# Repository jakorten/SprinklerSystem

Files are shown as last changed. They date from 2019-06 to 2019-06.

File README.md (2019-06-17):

# SprinklerSystem
Repository for valve controllers etc.

Here I publish updates to Python and Arduino scripts to create my / your own irrigation system.

## System parts
CinqueValvoleHAT is used to control a pump system.
TinyRelayModule is used to control a larger (230V) relay to switch of the main pump.
DueValvoleZeroBoard is used to control two valves and also features sensors.

## Progress and links

June 2019:
- CinqueValvoleHAT: 5x Valve/Tap Controller board (v1.0 / v1.1) (https://github.com/jakorten/SprinklerSystem/tree/master/CinqueValvoleHAT)
- DueValvoleZeroBoard: 2x Valve/Tap under development, uses a SAMD21 microcontroller and interfaces with a Raspberry Pi Zero (W).
- TinyRelayModule is only a solderboard version for now.

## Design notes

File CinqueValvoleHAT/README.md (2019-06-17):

# SprinklerSystem: CinqueValvoleHAT
Repository for valve controllers etc.

## About
Here I publish updates to Python and Arduino scripts to create my / your own irrigation system.

June 2019:
- 5x Tap Controller board (v1.0 / v1.1) (CinqueValvoleHAT)

The CinqueValvoleHAT is used to control up to 5 valves.
- Typical valves have DC motors
- They will switch of when the limit is reached (fully open or fully closed)
- The print was designed to control 12V valves

Other DC motors can also be controlled using this HAT.
We have tested the HAT for 12V and below.

Most parts can handle up to 50V but that is the maximum, of you would
want to control 48V you should change some parts:
- 0.1uF/50V
- 22uF/63V

We use a voltage divider in v1.1 for AOD417, for 12V that would not have been
necessary. The AOD417 protects against wrong polarity.

The input (suggested 5V - 12V) is not connected to the rest of the system only to the
DRV8871 drivers.

Each DRV8871 can handle up to 3.6A (but is limited to about 2A by the 30k resistors) and
has a maximum voltage of 50V (< 45V recommended). In case you want to use the HAT as is
for 48V motors we suggest you make sure your supply only divers 45V or less which should
be more than enough for ball valves. Note: We did not test this so use at your own risk.

We did try to run our 12V ball valves at 7V and although they move slower they will work
just fine.

We used the valves from:
https://nl.aliexpress.com/store/4032047?spm=a2g0o.detail.1000002.2.6d6b58daLNaQAn
(e.g. https://nl.aliexpress.com/item/32896353276.html?spm=a2g0s.9042311.0.0.32b34c4dLBPZam)

## Source
The source lets your Raspberry Pi control the valves via a PCA9685 IC

## Credits

Thanks @Adafruit for not only providing us with the basis idea and HAT layout (https://www.adafruit.com/product/2348).
Their hat works well but we found it got too hot inside the narrow enclosure we used.
Also thanks to @Adafruit for their suggestion to use DRV8871 drivers (they sell separate boards).

Note: we have designed the HAT and software to interoperate with homebridge. We use a second Raspberry Pi that
runs homebridge and will allow to set the valves remotely.

# ToDo: Work in progress
- We have created a HMI system for operation without homebridge
- We still need to integrate this functionality with the current source.
- Other parts of the system will be uploaded as we go.
- We hope to make the system available for purchase using Tindie.

Johan Korten<br>
June 2019

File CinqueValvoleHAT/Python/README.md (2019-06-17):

# SprinklerSystem: CinqueValvoleHAT
Controller for a CinqueValvoleHAT hat using python.

The controlServer.py will let you start a simple server on your Raspberry Pi.

http://hostname:8000/valves/valve=0&state=1 will set valve 1 to open
http://hostname:8000/valves/valve=0&state=0 will set valve 1 to closed

The tapHatCinqController defines five possible valves you can use.
You could stake more than one CinqueValvoleHAT but then you need a special stacking header of course.

We have not done that for now but it would be easy to change the source code to accommodate for that
(add parameter for your url that you e.g. call 'module', parse that variable and send commands to
the appropriate instance).

All taps have a timeout as defined in that init method:
self.motor1 = DRV8871_Valve(0, 15.0, tapState.open)

This means:
- self.motor1 is defined as motor 0
- has a timeout of 15.0 seconds
- default state is open (change to closed if you want to reverse how your valve reacts)

Johan Korten<br>
June 2019

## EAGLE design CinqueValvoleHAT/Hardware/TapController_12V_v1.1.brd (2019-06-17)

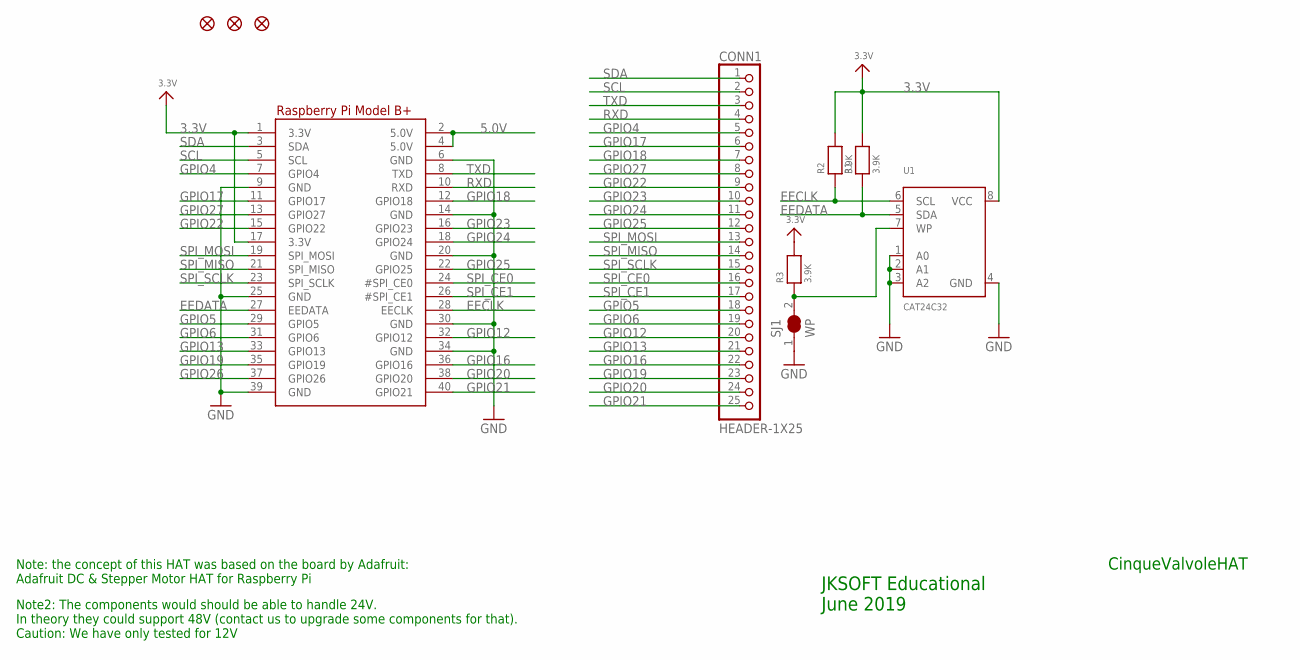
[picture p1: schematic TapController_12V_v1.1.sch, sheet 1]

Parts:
CONN1: HEADER-1X25; 1X25_ROUND_70MIL
FID1, FID2, FID3: FIDUCIAL""; FIDUCIAL_1MM
R1, R2, R3: 3.9K; 0805-NO@1
RPI1: RASPBERRYPI_BPLUS_HATSLOTS; PI_HAT_SLOTS
SJ1: WP; SOLDERJUMPER_CLOSEDWIRE
U1: CAT24C32; SOIC8_150MIL

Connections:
3.3V: R1.2, R2.2, R3.2, RPI1.1 (3.3V), RPI1.17 (3.3V), U1.8 (VCC); also elsewhere on the board
5.0V: RPI1.2 (5.0V), RPI1.4 (5.0V)
EECLK: R2.1, RPI1.28 (EECLK), U1.6 (SCL)
EEDATA: R1.1, RPI1.27 (EEDATA), U1.5 (SDA)
GND: RPI1.6 (GND), RPI1.9 (GND), RPI1.14 (GND), RPI1.20 (GND), RPI1.25 (GND), RPI1.30 (GND), RPI1.34 (GND), RPI1.39 (GND), SJ1.1, U1.1 (A0), U1.2 (A1), U1.3 (A2), U1.4 (GND); also elsewhere on the board
GPIO4: CONN1.5, RPI1.7 (GPIO4)
GPIO5: CONN1.18, RPI1.29 (GPIO5)
GPIO6: CONN1.19, RPI1.31 (GPIO6)
GPIO12: CONN1.20, RPI1.32 (GPIO12)
GPIO13: CONN1.21, RPI1.33 (GPIO13)
GPIO16: CONN1.22, RPI1.36 (GPIO16)
GPIO17: CONN1.6, RPI1.11 (GPIO17)
GPIO18: CONN1.7, RPI1.12 (GPIO18)
GPIO19: CONN1.23, RPI1.35 (GPIO19)
GPIO20: CONN1.24, RPI1.38 (GPIO20)
GPIO21: CONN1.25, RPI1.40 (GPIO21)
GPIO22: CONN1.9, RPI1.15 (GPIO22)
GPIO23: CONN1.10, RPI1.16 (GPIO23)
GPIO24: CONN1.11, RPI1.18 (GPIO24)
GPIO25: CONN1.12, RPI1.22 (GPIO25)
GPIO26: RPI1.37 (GPIO26)
GPIO27: CONN1.8, RPI1.13 (GPIO27)
unnamed: R3.1, SJ1.2, U1.7 (WP)
RXD: CONN1.4, RPI1.10 (RXD)
SCL: CONN1.2, RPI1.5 (SCL); also elsewhere on the board
SDA: CONN1.1, RPI1.3 (SDA); also elsewhere on the board
SPI_CE0: CONN1.16, RPI1.24 (#SPI_CE0)
SPI_CE1: CONN1.17, RPI1.26 (#SPI_CE1)
SPI_MISO: CONN1.14, RPI1.21 (SPI_MISO)
SPI_MOSI: CONN1.13, RPI1.19 (SPI_MOSI)
SPI_SCLK: CONN1.15, RPI1.23 (SPI_SCLK)
TXD: CONN1.3, RPI1.8 (TXD)

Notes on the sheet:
JKSOFT Educational June 2019
CinqueValvoleHAT
Note: the concept of this HAT was based on the board by Adafruit: Adafruit DC & Stepper Motor HAT for Raspberry Pi
Note2: The components would should be able to handle 24V. In theory they could support 48V (contact us to upgrade some components for that). Caution: We have only tested for 12V

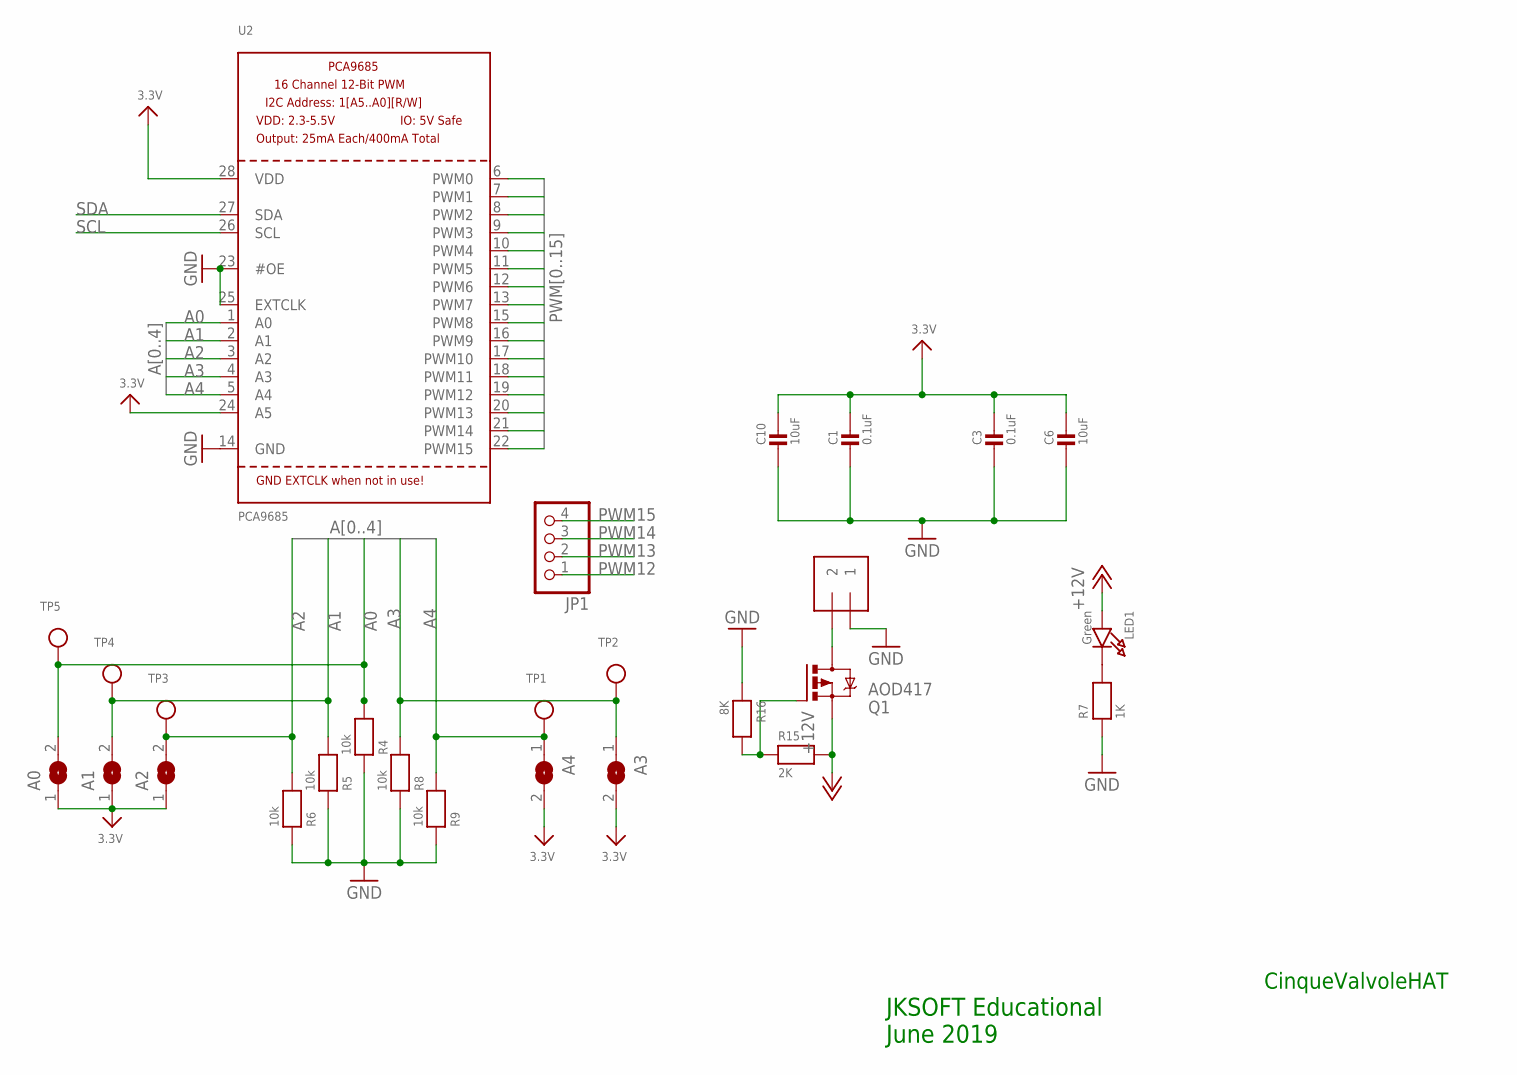
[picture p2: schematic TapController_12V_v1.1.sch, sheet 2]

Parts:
A0, A1, A2, A3, A4: SOLDERJUMPERREFLOW_NOPASTE; SOLDERJUMPER_REFLOW_NOPASTE
C1, C3: 0.1uF; 0805-NO
C6, C10: 10uF; 0805-NO
JP1: HEADER-1X476MIL; 1X04_ROUND_76
LED1: Green; CHIPLED_0805_NOOUTLINE
MPOWER: 1X2-3.5MM
Q1: AOD417; D-PAK_TO252AA
R4, R5, R6, R8, R9: 10k; 0805-NO@1
R7: 1K; 0805-NO@1
R15: 2K; 0805-NO@1
R16: 8K; 0805-NO@1
TP1, TP2, TP3, TP4, TP5: TESTPOINTROUND2MM; TESTPOINT_ROUND_2MM
U2: PCA9685; TSSOP28

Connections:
3.3V: A0.1, A1.1, A2.1, A3.2, A4.2, C1.1, C3.1, C6.1, C10.1, U2.24 (A5), U2.28 (VDD); also elsewhere on the board
12V: MPOWER.2, Q1.4 (D)
+12V: LED1.A, Q1.3 (S), R15.2; also elsewhere on the board
A0: A0.2, R4.2, TP5.P$1, U2.1 (A0)
A1: A1.2, R5.2, TP4.P$1, U2.2 (A1)
A2: A2.2, R6.2, TP3.P$1, U2.3 (A2)
A3: A3.1, R8.2, TP2.P$1, U2.4 (A3)
A4: A4.1, R9.2, TP1.P$1, U2.5 (A4)
GND: C1.2, C3.2, C6.2, C10.2, MPOWER.1, R4.1, R5.1, R6.1, R7.1, R8.1, R9.1, R16.1, U2.14 (GND), U2.23 (#OE), U2.25 (EXTCLK); also elsewhere on the board
unnamed: Q1.1 (G), R15.1, R16.2
unnamed: LED1.C, R7.2
PWM0: U2.6 (PWM0); also elsewhere on the board
PWM1: U2.7 (PWM1); also elsewhere on the board
PWM2: U2.8 (PWM2); also elsewhere on the board
PWM3: U2.9 (PWM3); also elsewhere on the board
PWM4: U2.10 (PWM4); also elsewhere on the board
PWM5: U2.11 (PWM5); also elsewhere on the board
PWM6: U2.12 (PWM6); also elsewhere on the board
PWM7: U2.13 (PWM7); also elsewhere on the board
PWM8: U2.15 (PWM8); also elsewhere on the board
PWM9: U2.16 (PWM9); also elsewhere on the board
PWM10: U2.17 (PWM10)
PWM11: U2.18 (PWM11)
PWM12: JP1.1, U2.19 (PWM12)
PWM13: JP1.2, U2.20 (PWM13)
PWM14: JP1.3, U2.21 (PWM14)
PWM15: JP1.4, U2.22 (PWM15)
SCL: U2.26 (SCL); also elsewhere on the board
SDA: U2.27 (SDA); also elsewhere on the board

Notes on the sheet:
JKSOFT Educational June 2019
CinqueValvoleHAT

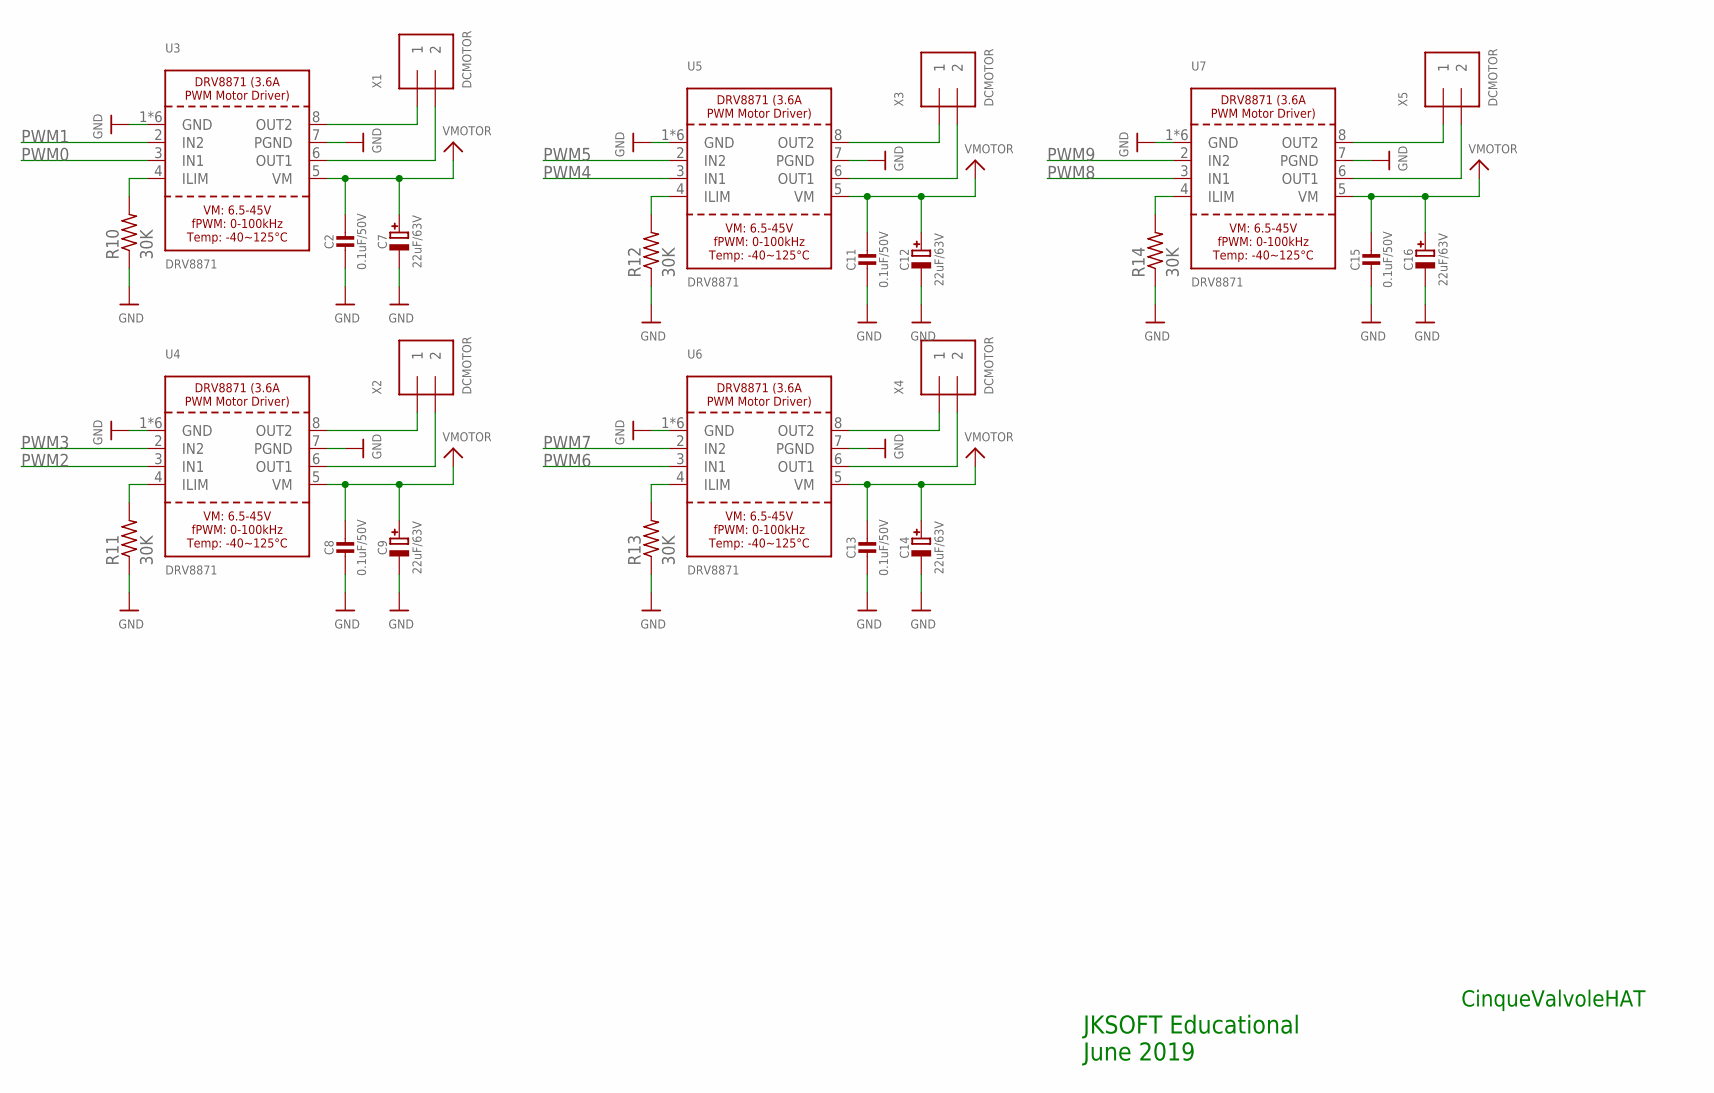
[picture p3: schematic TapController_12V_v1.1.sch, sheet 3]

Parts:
C2, C8, C11, C13, C15: 0.1uF/50V; 0805-NO
C7, C9, C12, C14, C16: 22uF/63V; PANASONIC_D
R10, R11, R12, R13, R14: 30K; R0805W
U3, U4, U5, U6, U7: DRV8871; HSOP8
X1, X2, X3, X4, X5: DCMOTOR; TERMBLOCK_1X2-3.5MM

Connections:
+12V: C2.1, C7.+, C8.1, C9.+, C11.1, C12.+, C13.1, C14.+, C15.1, C16.+, U3.5 (VM), U4.5 (VM), U5.5 (VM), U6.5 (VM), U7.5 (VM); also elsewhere on the board
GND: C2.2, C7.-, C8.2, C9.-, C11.2, C12.-, C13.2, C14.-, C15.2, C16.-, R10.1, R11.1, R12.1, R13.1, R14.1, U3.1 (GND), U3.7 (PGND), U3.GND, U3.P$1 (GND), U3.P$2 (GND), U3.P$3 (GND), U3.P$4 (GND), U4.1 (GND), U4.7 (PGND), U4.GND, U4.P$1 (GND), U4.P$2 (GND), U4.P$3 (GND), U4.P$4 (GND), U5.1 (GND), U5.7 (PGND), U5.GND, U5.P$1 (GND), U5.P$2 (GND), U5.P$3 (GND), U5.P$4 (GND), U6.1 (GND), U6.7 (PGND), U6.GND, U6.P$1 (GND), U6.P$2 (GND), U6.P$3 (GND), U6.P$4 (GND), U7.1 (GND), U7.7 (PGND), U7.GND, U7.P$1 (GND), U7.P$2 (GND), U7.P$3 (GND), U7.P$4 (GND); also elsewhere on the board
unnamed: R10.2, U3.4 (ILIM)
unnamed: R11.2, U4.4 (ILIM)
unnamed: R12.2, U5.4 (ILIM)
unnamed: R13.2, U6.4 (ILIM)
unnamed: R14.2, U7.4 (ILIM)
OUT1: U3.6 (OUT1), X1.2
OUT2: U3.8 (OUT2), X1.1
OUT3: U4.8 (OUT2), X2.1
OUT4: U4.6 (OUT1), X2.2
OUT5: U5.8 (OUT2), X3.1
OUT6: U5.6 (OUT1), X3.2
OUT7: U6.8 (OUT2), X4.1
OUT8: U6.6 (OUT1), X4.2
OUT9: U7.8 (OUT2), X5.1
OUT10: U7.6 (OUT1), X5.2
PWM0: U3.3 (IN1); also elsewhere on the board
PWM1: U3.2 (IN2); also elsewhere on the board
PWM2: U4.3 (IN1); also elsewhere on the board
PWM3: U4.2 (IN2); also elsewhere on the board
PWM4: U5.3 (IN1); also elsewhere on the board
PWM5: U5.2 (IN2); also elsewhere on the board
PWM6: U6.3 (IN1); also elsewhere on the board
PWM7: U6.2 (IN2); also elsewhere on the board
PWM8: U7.3 (IN1); also elsewhere on the board
PWM9: U7.2 (IN2); also elsewhere on the board

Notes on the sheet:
JKSOFT Educational June 2019
CinqueValvoleHAT

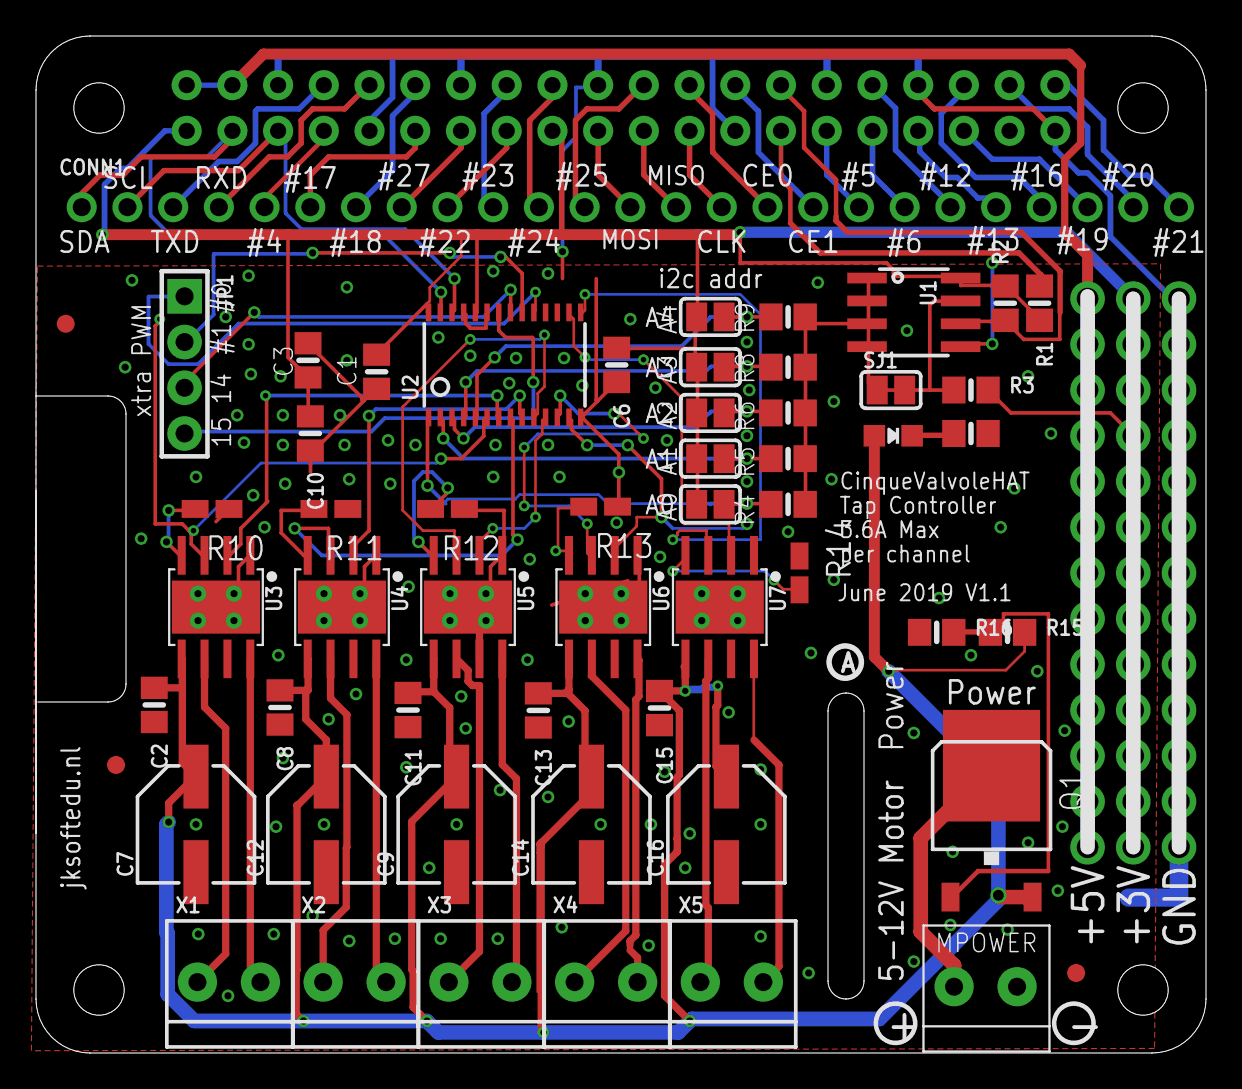
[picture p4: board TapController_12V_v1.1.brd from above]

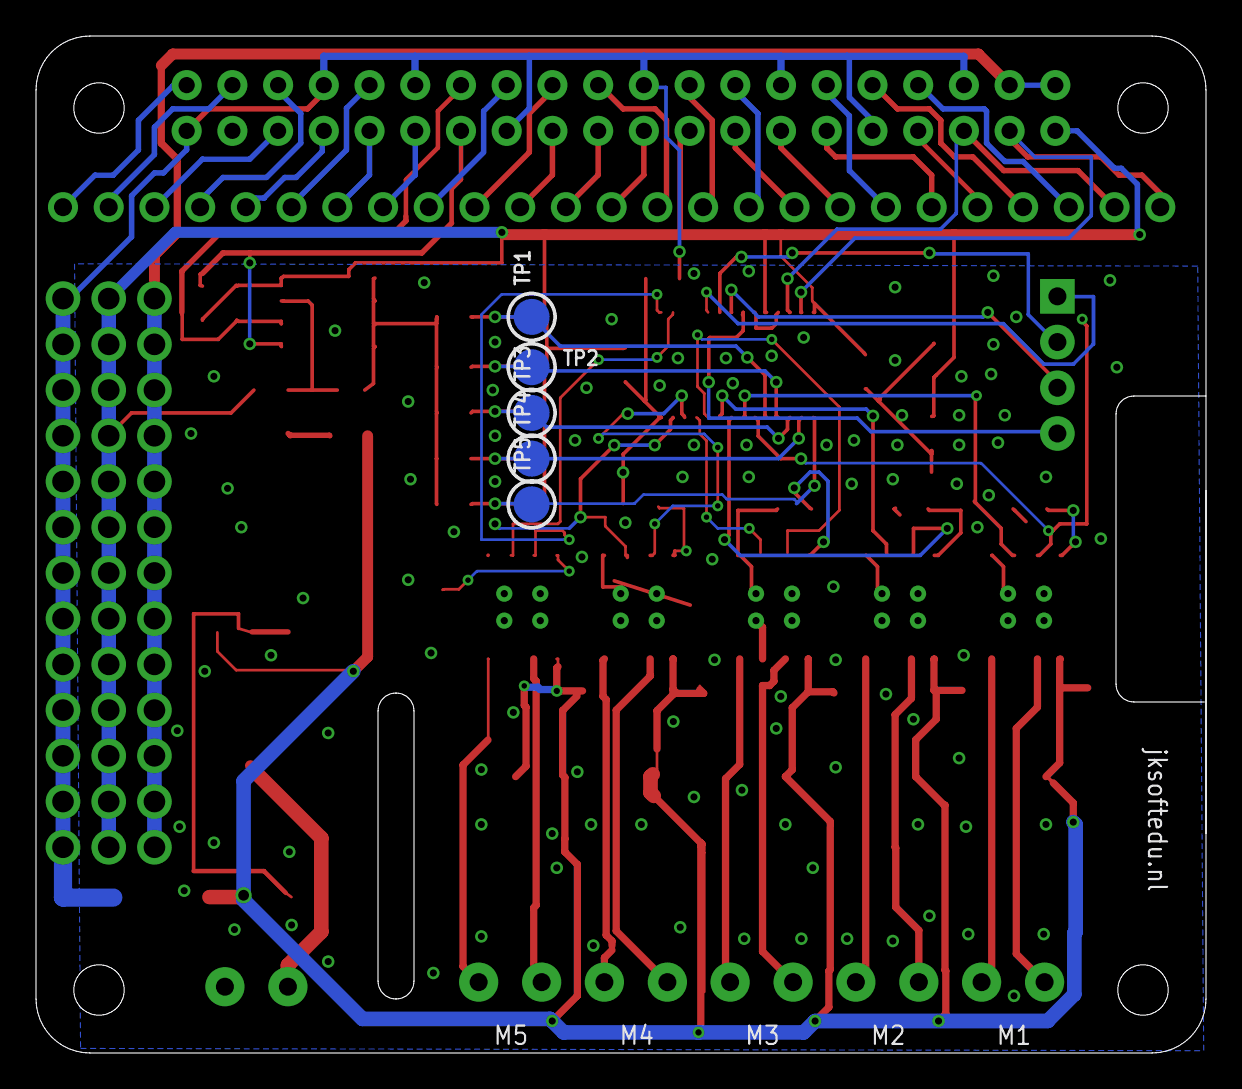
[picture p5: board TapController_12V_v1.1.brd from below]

Board: 2 copper layers, 65.0 x 56.5 mm, 63 parts (5 on the bottom side), 69 nets.

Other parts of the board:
U$6: PCBFEAT-REV-040

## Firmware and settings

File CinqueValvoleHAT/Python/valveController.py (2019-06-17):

import Adafruit_PCA9685
from enum import Enum     # for enum34, or the stdlib version
import pigpio
import time
import sys
import os
from threading import Timer,Thread,Event

deviceAddress = 0x60
enableDebugPrints = False

'''

J.A. Korten June 2019
V1.0 Controller for 5x Tap Valve (DC Motor) Controller
Note: this file can be used to use in stand alone mode (without e.g. the controlServer)

For TapController 12V v1.0:

+------------+------------+------------+------------+------------+
| Motor 1    | Motor 2    | Motor 3    | Motor 4    | Motor 5    |
+------------+------------+------------+------------+------------+
| PWM0 IN1.1 | PWM2 IN2.1 | PWM8 IN3.1 | PWM4 IN4.1 | PWM6 IN4.1 |
| PWM1 IN1.2 | PWM3 IN2.2 | PWM9 IN3.2 | PWM5 IN4.2 | PWM7 IN5.2 |
+------------+------------+------------+------------+------------+

For TapController 12V v1.1+:

+------------+------------+------------+------------+------------+
| Motor 1    | Motor 2    | Motor 3    | Motor 4    | Motor 5    |
+------------+------------+------------+------------+------------+
| PWM0 IN1.1 | PWM2 IN2.1 | PWM4 IN3.1 | PWM6 IN4.1 | PWM8 IN4.1 |
| PWM1 IN1.2 | PWM3 IN2.2 | PWM5 IN3.2 | PWM7 IN4.2 | PWM9 IN5.2 |
+------------+------------+------------+------------+------------+

https://www.tutorialspoint.com/python3/python_multithreading.htm

   Uses DRV8871 (Max 3.6A, limited at 2A)
   Theoretical Voltage limit 50V=.
   Board was intended for 5-12V

   Truth table for DRV8871:
   +------+------+-------+-------+----------+
   | IN 1 | IN 2 | OUT 1 | OUT 2 |          |
   +------+------+-------+-------+----------+
   |   0  |   0  | SLEEP | SLEEP | Disabled |
   |   0  |   1  | LOW   | HIGH  | Reverse  |
   |   1  |   0  | HIGH  | HIGH  | Forward  |
   |   1  |   1  | LOW   | LOW   | Brake    |
   +------+------+-------+-------+----------+


'''

class tapState(Enum):
    open = 1
    closed = 0

tapDelay = 15.0

def debugPrint(message):
    if (enableDebugPrints):
        print(message)

class motorTimer():

   def __init__(self,t,hFunction,name):
      self.t=t
      self.hFunction = hFunction
      self._name = str(name)
      debugPrint("Thread " + name + " initialized...")
      self.thread = Timer(self.t,self.handle_function)

   def handle_function(self):
      self.hFunction()
      debugPrint("Thread " + self._name + " function called...")
      self.thread = Timer(self.t,self.handle_function)
      self.thread.cancel()

   def start(self):
      debugPrint("Thread " + self._name + " started...")
      self.thread.start()

   def cancel(self):
      debugPrint("Thread " + self._name + " cancelled...")
      self.thread.cancel()

class DRV8871_Valve:
    # expects a kit# / motor#
    pwmPins_1_1 = [0, 2, 4, 6, 8] # for V1.1+
    pwmPins = [0, 2, 8, 4, 6]     # strange but is due to HAT v1.0 configuration...
    # Function with the timer

    def motorTimeout(self):
        debugPrint("Timeout issued (motorStop)")
        debugPrint("Delay: " + str(self._delay))
        self._mT = motorTimer(self._delay, self.motorStop, str(self._motor))
        self._mT.start()
        #self.motorStop()
        #self._motorTimeout.cancel()

    def __init__(self, motor, delay, state, version=1.0):
         if (version > 1.0):
             pwmPins = pwmPins_1_1
         self._motor = motor
         self._delay = delay
         self._state = state
         self._default_state = state
         self._pwm_controller = Adafruit_PCA9685.PCA9685(address=deviceAddress, busnum=1)

    def open(self):
        debugPrint(str(self))
        if (self._state == tapState.closed):
            self._motor.throttle = 1.0
            sleep(self._delay)
            self._state = tapState.open
            self._motor.throttle = 0

    def close(self):
        debugPrint(str(self))
        if (self._state == tapState.open):
            self._motor.throttle = -1.0
            sleep(self._delay)
            self._state = tapState.closed
            self._motor.throttle = 0

    def isClosed(self):
        return self._state == tapState.closed

    def isOpen(self):
        return self._state == tapState.open

    def release(self):
        self.release()

    def motorForward(self):
        in1 = 1
        in2 = 0
        self.sendCommand(in1, in2)

    def motorBackward(self):
        in1 = 0
        in2 = 1
        self.sendCommand(in1, in2)

    def motorBrake(self):
        in1 = 1
        in2 = 1
        self.sendCommand(in1, in2)

    def motorStop(self):
        in1 = 0
        in2 = 0
        self.sendCommand(in1, in2)
        debugPrint("Motorstop issued (" + str(self._motor) + ")")

    def setStateTimer(self, toState):
        try:
            self._mT.cancel() # just in case...
        except:
            # do nothing
            enableDebugPrints("Error: Timer exception")
        if (toState == self._default_state):
            self.motorBackward()
        else:
            self.motorForward()
        try:
            self.motorTimeout()
        except:
            debugPrint("Timeout issue...")

    def sendCommand(self, in1, in2):
        debugPrint("Send command...")
        # pwm frequency?!
        _pins0 = self.pwmPins[self._motor]   # get pwmPins + 0
        _pins1 = self.pwmPins[self._motor]+1 # get pwmPins + 1
        PCA9685_PWM_FULL = 0x1000
        if (in1 == 1):
            self._pwm_controller.set_pwm(_pins0, PCA9685_PWM_FULL, 0)
        else:
            self._pwm_controller.set_pwm(_pins0, 0, 0)
        if (in2 == 1):
            self._pwm_controller.set_pwm(_pins1, PCA9685_PWM_FULL, 0)
        else:
            self._pwm_controller.set_pwm(_pins1, 0, 0)

    def inRange(self, value, min, max):
        return (value >= min) and (value <= max)

class tapHatCinqController():
    def __init__(self):
        if (self.findPCA9685):
            self._error = False
            print(" PCA9685 was found")
        else:
            self._error = True
            print(" Error: Could not find PCA9685")
            return

        # DRV8871_Valve number, timeout delay, default state
        self.motor1 = DRV8871_Valve(0, 15.0, tapState.open)
        self.motor2 = DRV8871_Valve(1, 15.0, tapState.open)
        self.motor3 = DRV8871_Valve(2, 15.0, tapState.open)
        self.motor4 = DRV8871_Valve(3, 15.0, tapState.open)
        self.motor5 = DRV8871_Valve(4, 15.0, tapState.open)

    def stopMotors(self):
        self.motor1.motorStop()
        self.motor2.motorStop()
        self.motor3.motorStop()
        self.motor4.motorStop()
        self.motor5.motorStop()
        debugPrint("Motor stops issued: SUCCESS.")

    def setValve(self, tap, state):
        debugPrint("setValve: " + str(tap) + " to " + str(state) + ".")
        toState = tapState.closed
        if (state == 1):
            toState = tapState.open
        if (tap == 0):
            self.motor1.setStateTimer(toState)
        if (tap == 1):
            self.motor2.setStateTimer(toState)
        if (tap == 2):
            self.motor3.setStateTimer(toState)
        if (tap == 3):
            self.motor4.setStateTimer(toState)
        if (tap == 4):
            self.motor5.setStateTimer(toState)


    def findPCA9685(self):
        pi = pigpio.pi() # connect to local Pi
        for device in range(128):
              h = pi.i2c_open(1, device)
              try:
                 pi.i2c_read_byte(h)
                 if (inRange(device, 0x60, 0x70)):
                     #print("Possible PCA9685 found at: " + str(hex(device)))
                     deviceAddress = hex(device)
                     return True
                     pi.stop # disconnect from Pi
                 else:
                     #print("Other device found at: " + hex(device))
                     enableDebugPrints("Warning: Found some i2c device outside expected range...")
              except: # exception if i2c_read_byte fails
                 pass
              pi.i2c_close(h)
        pi.stop # disconnect from Pi
        return False


if __name__ == '__main__':
    try:
        pi = pigpio.pi()
        if not pi.connected:
            print("Start pigpio deamon first!")
            exit()
        print("======================================")
        print(" System reports: pigpio deamon found!")

        print(" 5x Motor Controller HAT started.")
        testControl = tapHatCinqController()
        if (testControl._error == False):
            print(" Communication with PCA9685 OK")
            print("======================================")
        else:
            sys.exit(0)
        motor = testControl.motor5
        while True:
            motor.motorForward()
            print("motorForward")
            time.sleep(5)

            motor.motorStop()
            print("motorStop")
            time.sleep(1)

            motor.motorBackward()
            print("motorBackward")
            time.sleep(5)

            motor.motorStop()
            print("motorStop")
            time.sleep(1)
    except KeyboardInterrupt:
        print("Script was Interrupted...")
        testControl.stopMotors() # note: do not forget this otherwise motor might still be powered...
        try:
            sys.exit(0)
        except SystemExit:
            os._exit(0)
'''
result = findPCA9685()
if (result):
    print("Found at address " + str(hex(deviceAddress)))
else:
    print("Not found")
'''

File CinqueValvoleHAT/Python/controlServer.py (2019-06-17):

import time
import json
from http.server import BaseHTTPRequestHandler, HTTPServer
from urllib.parse import urlparse
#from TapControl.ControlTap import updateTap
from valveControl import *
import socket
import pigpio

HOST_NAME = 'pumptapunit' # note: change to appropriate hostname
PORT_NUMBER = 8000

'''
    J.A. Korten 2019

'''

enableDebugPrints = False

def debugPrint(message):
    if (enableDebugPrints):
        print(message)

class ValveServerHandler(BaseHTTPRequestHandler):

    def do_HEAD(self):
        self.send_response(200)
        self.send_header('Content-type', 'text/html')
        self.end_headers()

    def do_GET(self):
        paths = {
            #'/soilsensor': {'status': 200},
            #'/sensordata': {'status': 200},
            '/valves/': {'status': 200}
        }

        if self.path in paths:
            self.respond(paths[self.path])
        else:
            try:
                self.respond({'status': 200})
            except BrokenPipeError:
            	debugPrint("Whoops: broken server pipe...")

    def handle_http(self, status_code, path):
        info = "<b>Tiny Webserver for valve control</b><br><br>/valves/valve=x&state=y where valve x is 0..4 and state y is open=0..close=1<br><br>see: <a href='http://www.jksoftedu.nl' target='_blank'>JKSOFT Edu</a> for more information..."
        content = info
        if (path.find("/valves/") == 0):
            url = urlparse(path)
            content = str(url)

            # parameters:
            try:
                tapIndex   = path.index("valve=") + 6
                stateIndex = path.index("state=") + 6

                tap = int(path[tapIndex])
                state = int(path[stateIndex])
                content = "Cannot set tap " + str(tap) + " to " + str(state) + "!"
                if ((0 <= tap <= 4) and (0 <= state <= 1)):
                    content = "Setting tap " + str(tap) + " to " + str(state) + "!"
                    debugPrint(content)
                    try:
                        global valveController
                        valveController.setValve(tap, state)
                    except:
                        debugPrint("Error: Issue setting valve...")
                    debugPrint("tap: " + str(tap))
                    debugPrint("tap state: " + str(state))
                    content = "Setting tap " + str(tap) + " to " + str(state) + " now..."
                    #updateTap(0, tap, state)

            except:
                content = "Error setting tap state...<br><br>" + info
            # check parameters
        return bytes(content, 'UTF-8')

    def respond(self, opts):
        self.do_HEAD()
        response = self.handle_http(opts['status'], self.path)
        self.wfile.write(response)


valveController = tapHatCinqController()

if __name__ == '__main__':
    server_class = HTTPServer
    HOST_NAME = socket.gethostname() # just to be sure...
    pi = pigpio.pi()
    if not pi.connected:
        print("Warning: pigpio is not running, start pigpio deamon and restart server...")
        exit() # or reporting the issue
    httpd = server_class((HOST_NAME, PORT_NUMBER), ValveServerHandler)
    print(time.asctime(), 'Server Starts - %s:%s' % (HOST_NAME, PORT_NUMBER))
    try:
        httpd.serve_forever()
    except KeyboardInterrupt:
        pass
    httpd.server_close()
    print(time.asctime(), 'Server Stops - %s:%s' % (HOST_NAME, PORT_NUMBER))

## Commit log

2019-06-17 Initial commit
    Updates
    [TapController_12V_v1.1.brd, TapController_12V_v1.1.sch]
2019-06-20 update debug print
    update debug print

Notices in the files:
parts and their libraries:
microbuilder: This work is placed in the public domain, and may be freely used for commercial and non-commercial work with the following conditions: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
